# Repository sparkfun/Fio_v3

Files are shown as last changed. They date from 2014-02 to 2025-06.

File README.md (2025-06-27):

Fio v3
======

[Fio v3  
*Fio v3-ATmega32U4 (DEV-11520)*](https://www.sparkfun.com/products/11520)

The Fio v3 is a ATmega32U4 powered system, similar to the ARduino Fio. This board is compatible with a Lipo battery and XBees, and 
runs at 3.3v and 8MHz. 

Repository Contents
-------------------
* **/Firmware** - Arduino example code used in the hookup guide
* **/Hardware** - All Eagle design files (.brd, .sch, .STL)
* **/Production** - Test bed files and production panel files

Documentation
--------------
* **[Hookup Guide](https://learn.sparkfun.com/tutorials/pro-micro--fio-v3-hookup-guide)** - Basic hookup guide for the FioV3.
* **[SparkFun Arduino Board Addon](https://github.com/sparkfun/Arduino_Boards/)** - Arduino board addon for FioV3.
 
License Information
-------------------
This product is _**open source**_! 

Please review the LICENSE.md file for license information. 

If you have any questions or concerns on licensing, please contact techsupport@sparkfun.com.

Distributed as-is; no warranty is given.

- Your friends at SparkFun.

_<COLLABORATION CREDIT>_

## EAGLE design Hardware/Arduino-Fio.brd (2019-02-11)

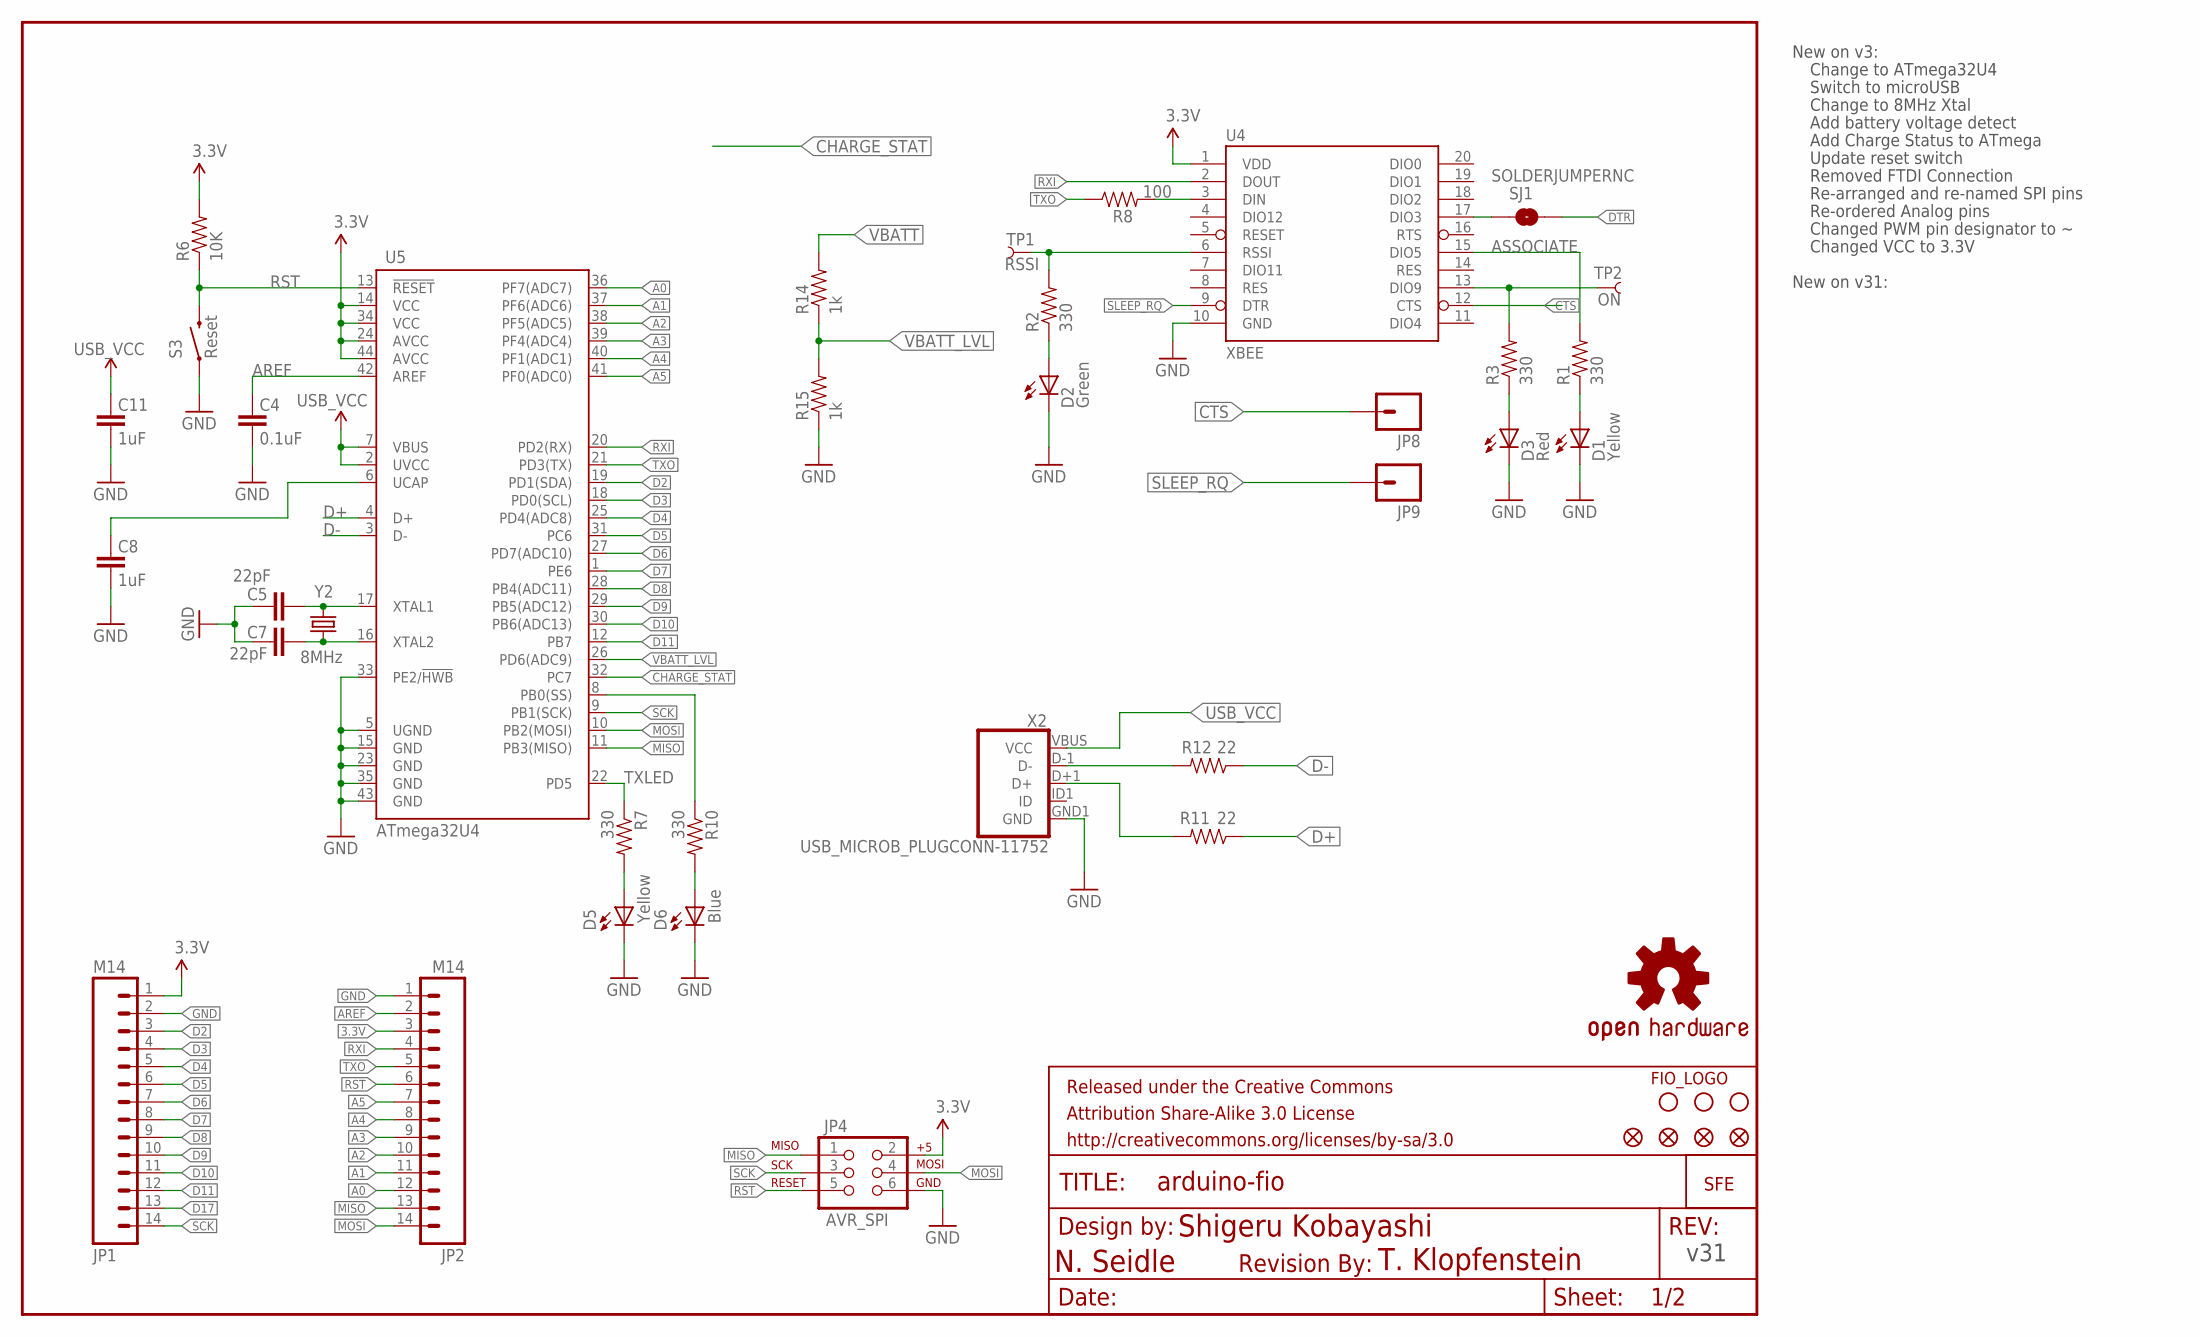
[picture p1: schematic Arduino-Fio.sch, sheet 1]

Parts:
C4: 0.1uF; 0603-CAP
C5, C7: 22pF; 0603-CAP
C8, C11: 1uF; 0603-CAP
D1, D5: Yellow; LED-0603
D2: Green; LED-0603
D3: Red; LED-0603
D6: Blue; LED-0603
FRAME1: FRAME-LETTER; CREATIVE_COMMONS
JP1, JP2: M14; 1X14
JP4: AVR_SPI; 2X3
JP5, JP16, JP17: STAND-OFF
JP8, JP9: M01PTH; 1X01
JP10, JP11, JP12, JP13: FIDUCIALUFIDUCIAL; FIDUCIAL-1X2
LOGO1: OSHW-LOGOL; OSHW-LOGO-L
R1, R2, R3, R7, R10: 330; 0603-RES
R6: 10K; 0603-RES
R8: 100; 0603-RES
R11, R12: 22; 0603-RES
R14, R15: 1k; 0603-RES
S3: Reset; TACTILE_SWITCH_SMD
SJ1: SOLDERJUMPERNC; SJ_2S
TP1: RSSI; PAD.03X.05
TP2: ON; PAD.03X.05
U4: XBEE; XBEE-SMD
U5: ATmega32U4; QFN-44-NOPAD_1:1
U$1: LOGO-SFENEW; SFE-NEW-WEBLOGO
U$2: REVISION
U$6: FIO_LOGOV2; FUNNEL_LOGO_BOTTOM_V2
X2: USB_MICROB_PLUGCONN-11752; USB-B-MICRO-SMD_V03
Y2: 8MHz; CRYSTAL-SMD-5X3

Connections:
3.3V: JP1.1, JP2.3, JP4.2, R6.2, U4.1 (VDD), U5.14 (VCC), U5.24 (AVCC), U5.34 (VCC), U5.44 (AVCC); also elsewhere on the board
A0: JP2.12, U5.36 (PF7(ADC7))
A1: JP2.11, U5.37 (PF6(ADC6))
A2: JP2.10, U5.38 (PF5(ADC5))
A3: JP2.9, U5.39 (PF4(ADC4))
A4: JP2.8, U5.40 (PF1(ADC1))
A5: JP2.7, U5.41 (PF0(ADC0))
AREF: C4.2, JP2.2, U5.42 (AREF)
ASSOCIATE: R1.2, U4.15 (DIO5)
CHARGE_STAT: U5.32 (PC7); also elsewhere on the board
CTS: JP8.1, U4.12 (CTS)
D2: JP1.3, U5.19 (PD1(SDA))
D3: JP1.4, U5.18 (PD0(SCL))
D4: JP1.5, U5.25 (PD4(ADC8))
D5: JP1.6, U5.31 (PC6)
D6: JP1.7, U5.27 (PD7(ADC10))
D7: JP1.8, U5.1 (PE6)
D8: JP1.9, U5.28 (PB4(ADC11))
D9: JP1.10, U5.29 (PB5(ADC12))
D10: JP1.11, U5.30 (PB6(ADC13))
D11: JP1.12, U5.12 (PB7)
D17: JP1.13, R10.1, U5.8 (PB0(SS))
D+: R11.1, U5.4 (D+)
D-: R12.1, U5.3 (D-)
DTR: SJ1.2
GND: C4.1, C5.2, C7.2, C8.1, C11.1, D1.C, D2.C, D3.C, D5.C, D6.C, JP1.2, JP2.1, JP4.6, R15.1, S3.1, U4.10 (GND), U5.5 (UGND), U5.15 (GND), U5.23 (GND), U5.33 (PE2/!HWB), U5.35 (GND), U5.43 (GND), X2.GND1 (GND); also elsewhere on the board
MISO: JP2.13, JP4.1, U5.11 (PB3(MISO))
MOSI: JP2.14, JP4.4, U5.10 (PB2(MOSI))
unnamed: R3.2, TP2.P$1, U4.13 (DIO9)
unnamed: D1.A, R1.1
unnamed: D2.A, R2.1
unnamed: R2.2, TP1.P$1, U4.6 (RSSI)
unnamed: R11.2, X2.D+1 (D+)
unnamed: D3.A, R3.1
unnamed: R8.2, U4.3 (DIN)
unnamed: SJ1.1, U4.17 (DIO3)
unnamed: D5.A, R7.2
unnamed: C7.1, U5.16 (XTAL2), Y2.1
unnamed: C5.1, U5.17 (XTAL1), Y2.3 (2)
unnamed: D6.A, R10.2
unnamed: R12.2, X2.D-1 (D-)
RST: JP2.6, JP4.5, R6.1, S3.3 (2), U5.13 (!RESET)
RXI: JP2.4, U4.2 (DOUT), U5.20 (PD2(RX))
SCK: JP1.14, JP4.3, U5.9 (PB1(SCK))
SLEEP_RQ: JP9.1, U4.9 (DTR)
TXLED: R7.1, U5.22 (PD5)
TXO: JP2.5, R8.1, U5.21 (PD3(TX))
UCAP: C8.2, U5.6 (UCAP)
USB_VCC: C11.2, U5.2 (UVCC), U5.7 (VBUS), X2.VBUS (VCC); also elsewhere on the board
VBATT: R14.2; also elsewhere on the board
VBATT_LVL: R14.1, R15.2, U5.26 (PD6(ADC9))

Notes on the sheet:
Shigeru Kobayashi
Change to ATmega32U4
Switch to microUSB
New on v3:
Change to 8MHz Xtal
Add battery voltage detect
Add Charge Status to ATmega
Update reset switch
Removed FTDI Connection
Re-arranged and re-named SPI pins
Re-ordered Analog pins
Changed PWM pin designator to ~
Changed VCC to 3.3V
New on v31:
v31
N. Seidle
T. Klopfenstein

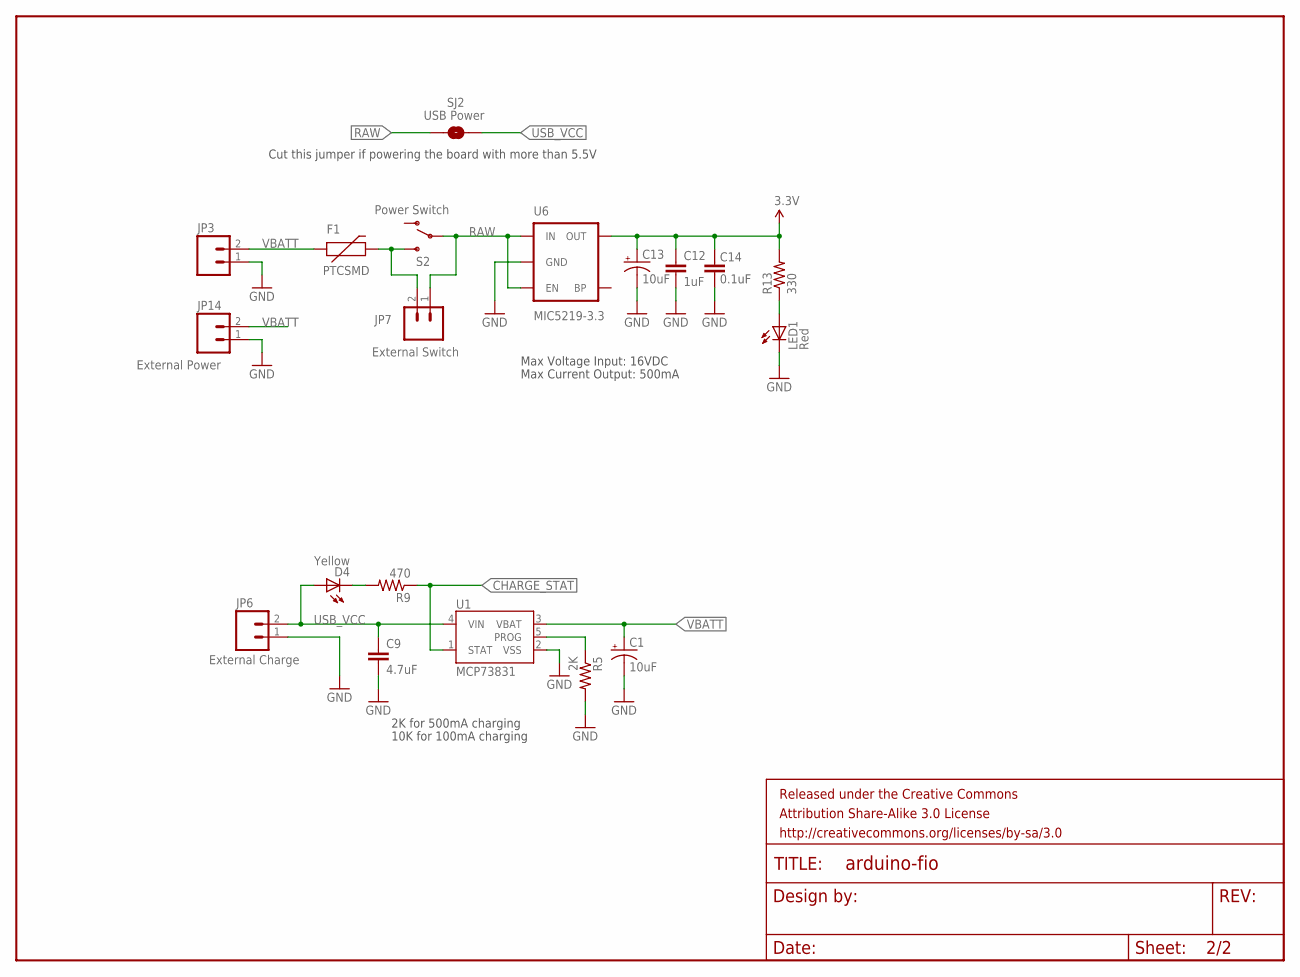
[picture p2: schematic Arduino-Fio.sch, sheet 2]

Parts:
C1, C13: 10uF; EIA3216
C9: 4.7uF; 0603-CAP
C12: 1uF; 0603-CAP
C14: 0.1uF; 0603-CAP
D4: Yellow; LED-0603
F1: PTCSMD; PTC-1206
FRAME2: FRAME-LETTER; CREATIVE_COMMONS
JP3: M02-JST-2MM-SMT; JST-2-SMD
JP6: External Charge; 1X02
JP7: External Switch; 1X02
JP14: External Power; 1X02
LED1: Red; LED-0603
R5: 2K; 0603-RES
R9: 470; 0603-RES
R13: 330; 0603-RES
S2: Power Switch; AYZ0202
SJ2: USB Power; SJ_2S-TRACE
U1: MCP73831; SOT23-5
U6: MIC5219-3.3; SOT23-5

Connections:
3.3V: C12.1, C13.A (+), C14.2, R13.2, U6.5 (OUT); also elsewhere on the board
CHARGE_STAT: R9.1, U1.1 (STAT); also elsewhere on the board
GND: C1.C (-), C9.2, C12.2, C13.C (-), C14.1, JP3.1, JP6.1, JP14.1, LED1.C, R5.2, U1.2 (VSS), U6.2 (GND); also elsewhere on the board
unnamed: D4.C, R9.2
unnamed: F1.2, JP7.2, S2.3 (S)
unnamed: R5.1, U1.5 (PROG)
unnamed: LED1.A, R13.1
RAW: JP7.1, S2.2, SJ2.1, U6.1 (IN), U6.3 (EN)
USB_VCC: C9.1, D4.A, JP6.2, SJ2.2, U1.4 (VIN); also elsewhere on the board
VBATT: C1.A (+), F1.1, JP3.2, JP14.2, U1.3 (VBAT); also elsewhere on the board

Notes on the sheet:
Max Voltage Input: 16VDC
Max Current Output: 500mA
Cut this jumper if powering the board with more than 5.5V
2K for 500mA charging
10K for 100mA charging

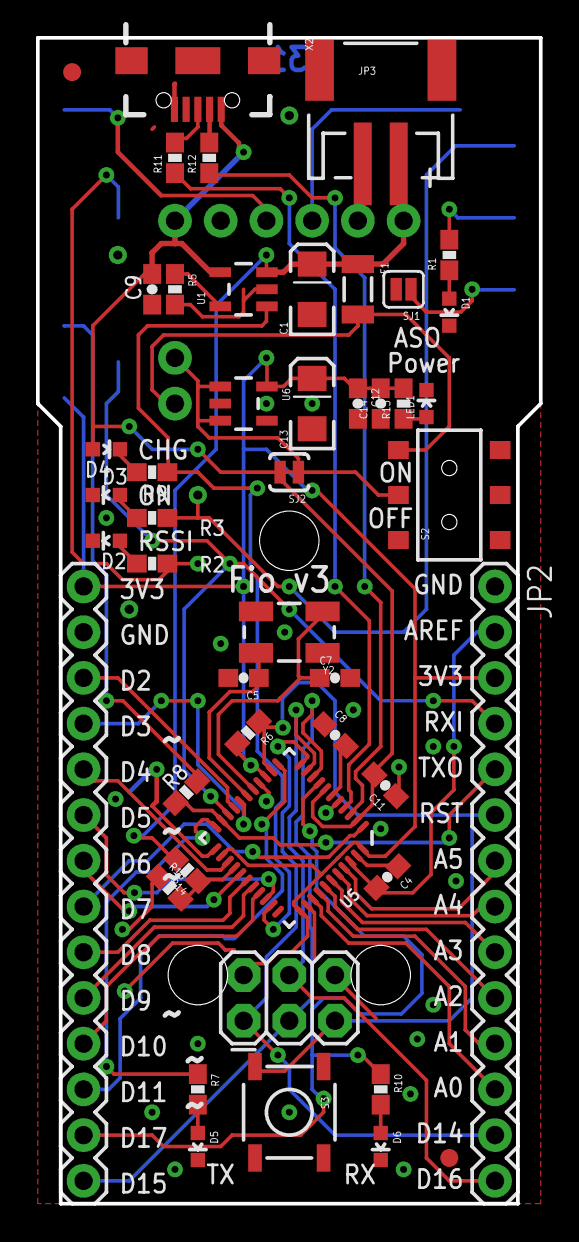
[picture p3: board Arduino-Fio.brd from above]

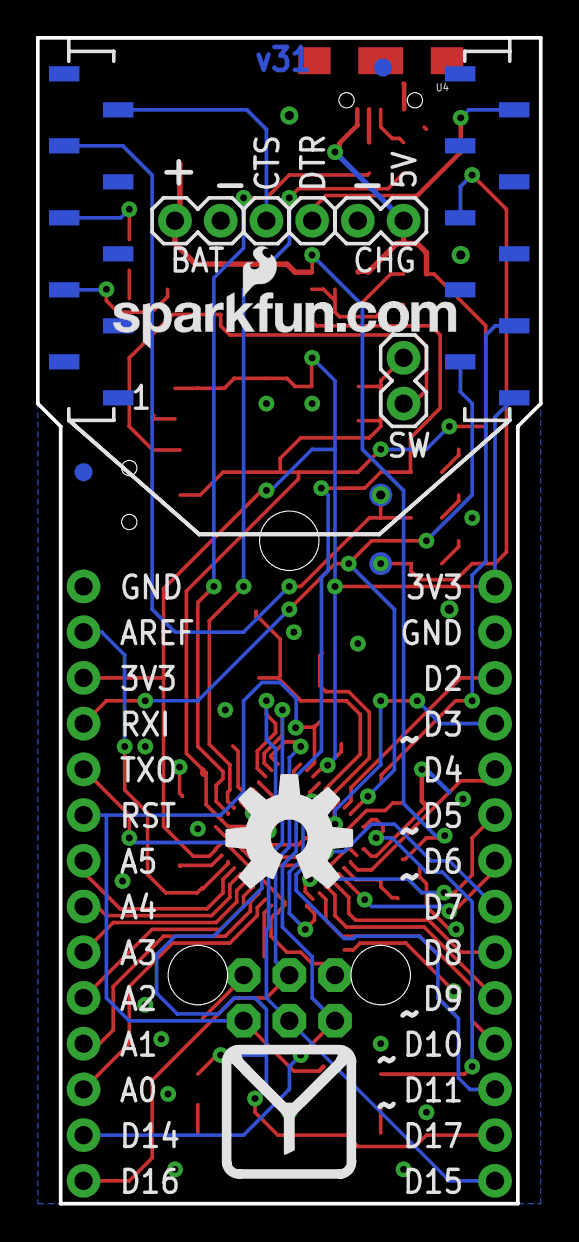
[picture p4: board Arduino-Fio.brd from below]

Board: 2 copper layers, 27.9 x 64.8 mm, 66 parts (12 on the bottom side), 55 nets.

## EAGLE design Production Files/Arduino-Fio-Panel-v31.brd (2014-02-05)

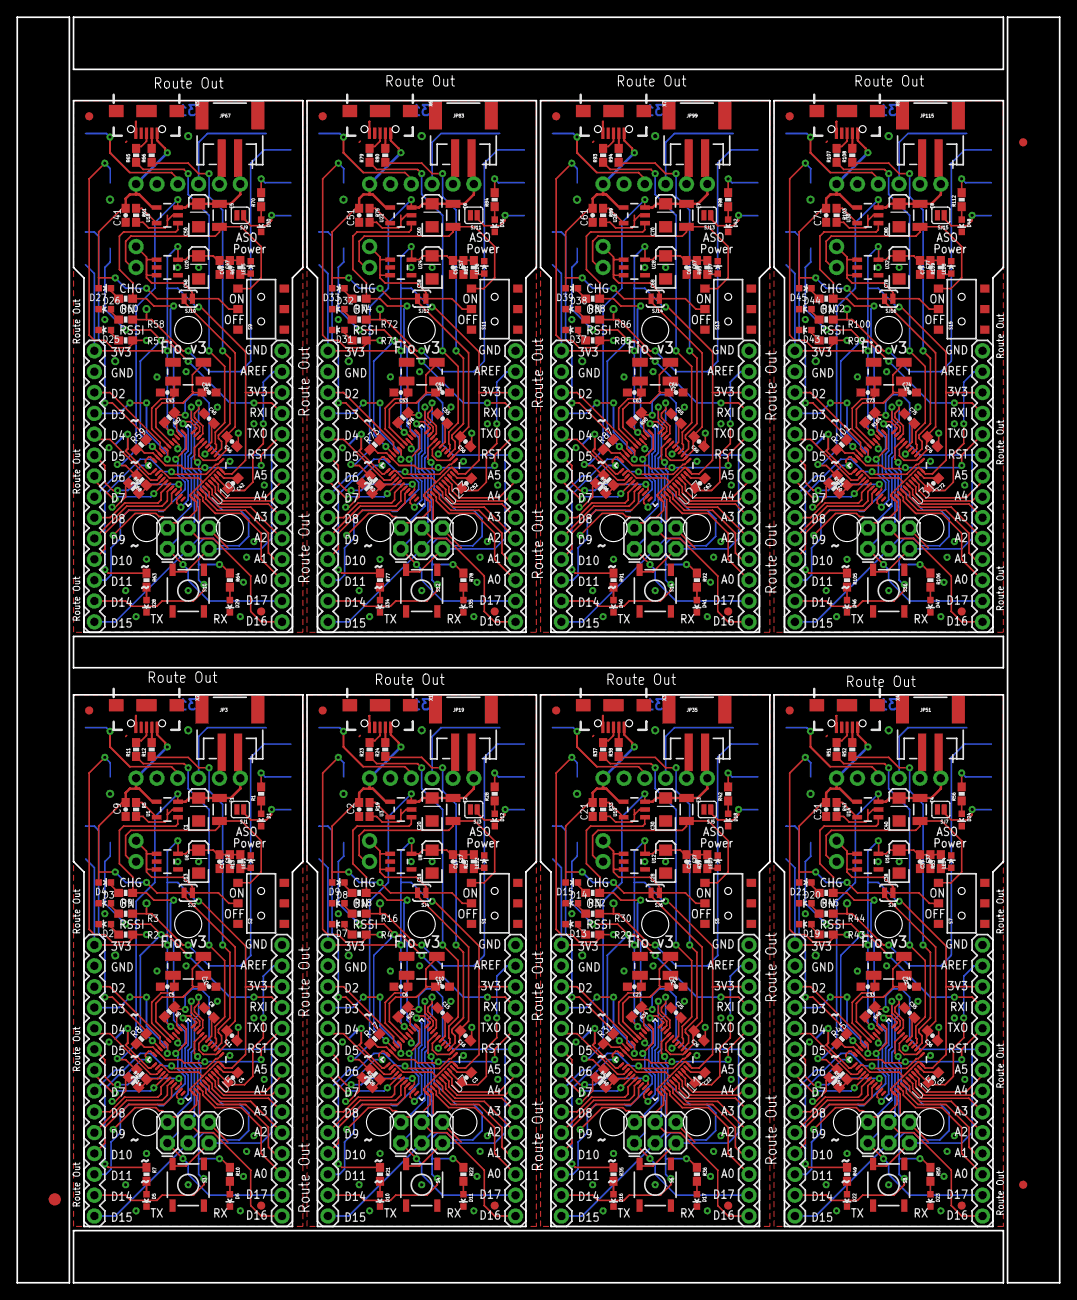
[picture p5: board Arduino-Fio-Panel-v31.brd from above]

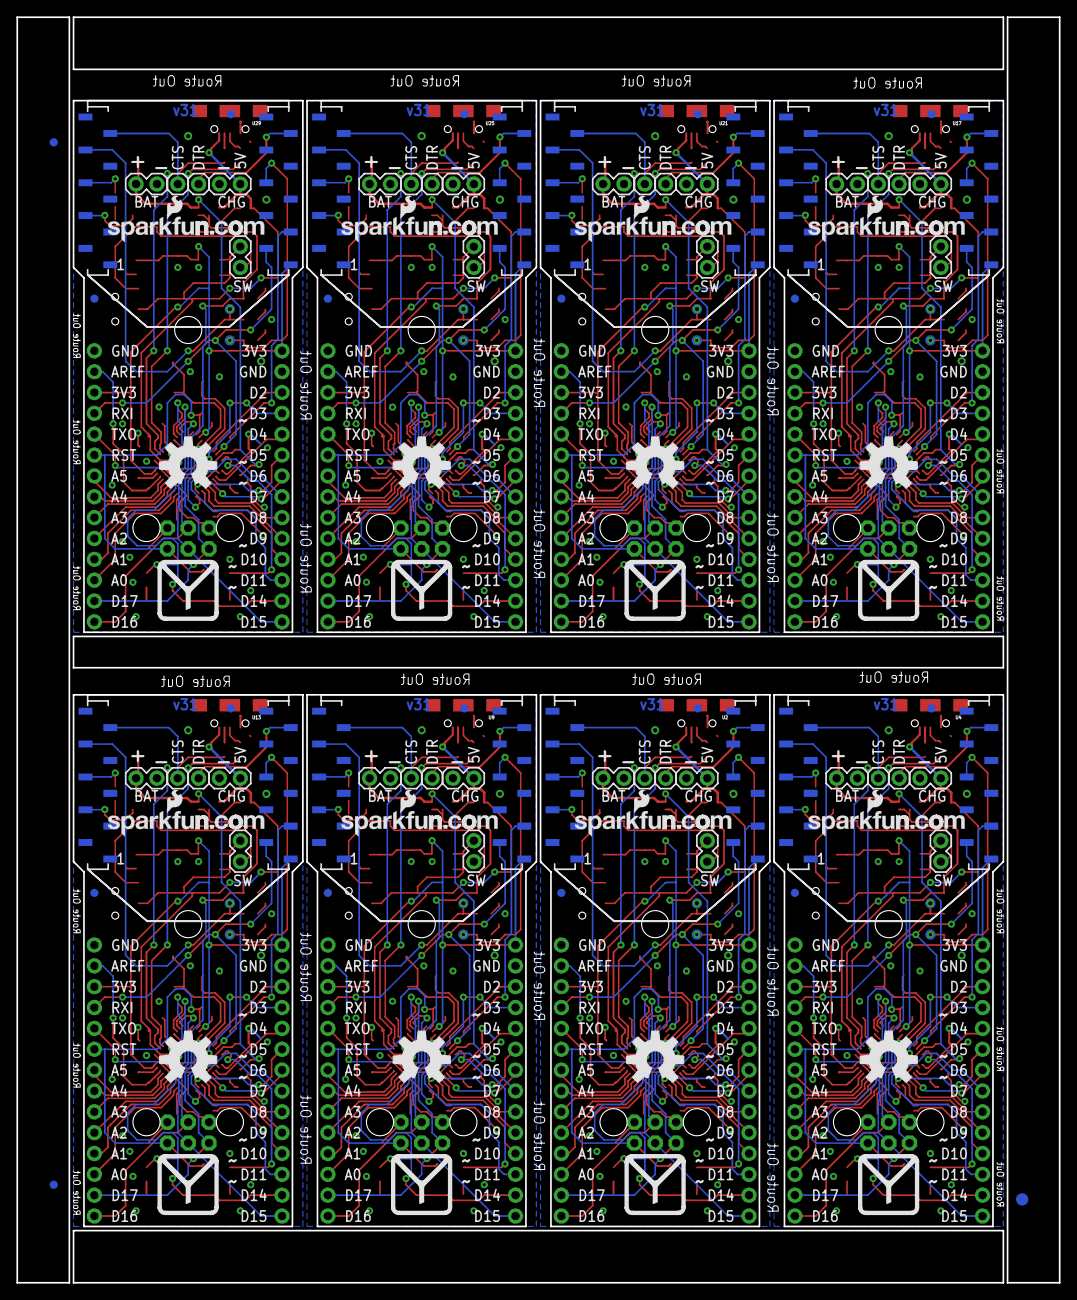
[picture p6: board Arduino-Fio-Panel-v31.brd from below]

Board: 2 copper layers, 127.0 x 154.2 mm, 510 parts (99 on the bottom side), 440 nets.

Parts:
C1, C13, C18, C20, C28, C30, C38, C40, C48, C50, C58, C60, C68, C70, C78, C80: 10uF; EIA3216
C2, C9, C21, C31, C41, C51, C61, C71: 4.7uF; 0603-CAP
C3, C4, C14, C19, C22, C29, C32, C39, C42, C49, C52, C59, C62, C69, C72, C79: 0.1uF; 0603-CAP
C5, C6, C7, C10, C23, C24, C33, C34, C43, C44, C53, C54, C63, C64, C73, C74: 22pF; 0603-CAP
C8, C11, C12, C15, C16, C17, C25, C26, C27, C35, C36, C37, C45, C46, C47, C55, C56, C57, C65, C66, C67, C75, C76, C77: 1uF; 0603-CAP
D1, D4, D5, D9, D10, D12, D15, D16, D18, D21, D22, D24, D27, D28, D30, D33, D34, D36, D39, D40, D42, D45, D46, D48: Yellow; LED-0603
D2, D7, D13, D19, D25, D31, D37, D43: Green; LED-0603
D3, D8, D14, D20, D26, D32, D38, D44: Red; LED-0603
D6, D11, D17, D23, D29, D35, D41, D47: Blue; LED-0603
E$1, E$2: FIDUCIAL-1.5X3
E$3, E$4, E$5, E$6: FIDUCIAL-1X2
F1, F2, F3, F4, F5, F6, F7, F8: PTCSMD; PTC-1206
JP1, JP2, JP18, JP29, JP34, JP45, JP50, JP61, JP66, JP77, JP82, JP93, JP98, JP109, JP114, JP125: M14; 1X14
JP3, JP19, JP35, JP51, JP67, JP83, JP99, JP115: JST-2-SMD
JP4, JP15, JP33, JP49, JP65, JP81, JP97, JP113: AVR_SPI; 2X3
JP5, JP16, JP17, JP30, JP31, JP32, JP46, JP47, JP48, JP62, JP63, JP64, JP78, JP79, JP80, JP94, JP95, JP96, JP110, JP111, JP112, JP126, JP127, JP128: STAND-OFF
JP6, JP21, JP37, JP53, JP69, JP85, JP101, JP117: External Charge; 1X02
JP7, JP22, JP38, JP54, JP70, JP86, JP102, JP118: External Switch; 1X02
JP8, JP9, JP23, JP24, JP39, JP40, JP55, JP56, JP71, JP72, JP87, JP88, JP103, JP104, JP119, JP120: 1X01
JP10, JP11, JP12, JP13, JP25, JP26, JP27, JP28, JP41, JP42, JP43, JP44, JP57, JP58, JP59, JP60, JP73, JP74, JP75, JP76, JP89, JP90, JP91, JP92, JP105, JP106, JP107, JP108, JP121, JP122, JP123, JP124: FIDUCIALUFIDUCIAL; FIDUCIAL-1X2
JP14, JP20, JP36, JP52, JP68, JP84, JP100, JP116: External Power; 1X02
LED1, LED2, LED3, LED4, LED5, LED6, LED7, LED8: Red; LED-0603
LOGO1, LOGO2, LOGO3, LOGO4, LOGO5, LOGO6, LOGO7, LOGO8: OSHW-LOGOL; OSHW-LOGO-L
R1, R2, R3, R4, R7, R10, R13, R16, R21, R22, R25, R28, R29, R30, R35, R36, R39, R42, R43, R44, R49, R50, R53, R56, R57, R58, R63, R64, R67, R70, R71, R72, R77, R78, R81, R84, R85, R86, R91, R92, R95, R98, R99, R100, R105, R106, R109, R112: 330; 0603-RES
R5, R19, R33, R47, R61, R75, R89, R103: 2K; 0603-RES
R6, R20, R34, R48, R62, R76, R90, R104: 10K; 0603-RES
R8, R17, R31, R45, R59, R73, R87, R101: 100; 0603-RES
R9, R18, R32, R46, R60, R74, R88, R102: 470; 0603-RES
R11, R12, R23, R24, R37, R38, R51, R52, R65, R66, R79, R80, R93, R94, R107, R108: 22; 0603-RES
R14, R15, R26, R27, R40, R41, R54, R55, R68, R69, R82, R83, R96, R97, R110, R111: 1k; 0603-RES
S1, S2, S5, S7, S9, S11, S13, S15: Power Switch; AYZ0202
S3, S4, S6, S8, S10, S12, S14, S16: Reset; TACTILE_SWITCH_SMD
SJ1, SJ3, SJ5, SJ7, SJ9, SJ11, SJ13, SJ15: SOLDERJUMPERNC; SJ_2S
SJ2, SJ4, SJ6, SJ8, SJ10, SJ12, SJ14, SJ16: USB Power; SJ_2S-TRACE
TP1, TP3, TP5, TP7, TP9, TP11, TP13, TP15: RSSI; PAD.03X.05
TP2, TP4, TP6, TP8, TP10, TP12, TP14, TP16: ON; PAD.03X.05
U1, U3, U10, U14, U18, U22, U26, U30: MCP73831; SOT23-5
U2, U4, U9, U13, U17, U21, U25, U29: XBEE; XBEE-SMD
U5, U7, U11, U15, U19, U23, U27, U31: ATMEGA32U4; QFN-44-NOPAD_1:1
U6, U8, U12, U16, U20, U24, U28, U32: MIC5219-3.3; SOT23-5
U$1, U$2, U$4, U$7, U$9, U$11, U$13, U$15: LOGO-SFENEW; SFE-NEW-WEBLOGO
U$3, U$5, U$6, U$8, U$10, U$12, U$14, U$16: FIO_LOGOV2; FUNNEL_LOGO_BOTTOM_V2
X1, X2, X3, X4, X5, X6, X7, X8: USB_MICROB_PLUGCONN-11752; USB-B-MICRO-SMD_V03
Y1, Y2, Y3, Y4, Y5, Y6, Y7, Y8: 8MHz; CRYSTAL-SMD-5X3

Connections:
3.3V: C12.1, C13.A, C14.2, JP1.1, JP2.3, JP4.2, R6.2, R13.2, U4.1, U5.14, U5.24, U5.34, U5.44, U6.5
3.3V1: C17.1, C18.A, C19.2, JP15.2, JP18.1, JP29.3, R20.2, R25.2, U2.1, U7.14, U7.24, U7.34, U7.44, U8.5
3.3V2: C27.1, C28.A, C29.2, JP33.2, JP34.1, JP45.3, R34.2, R39.2, U9.1, U11.14, U11.24, U11.34, U11.44, U12.5
3.3V3: C37.1, C38.A, C39.2, JP49.2, JP50.1, JP61.3, R48.2, R53.2, U13.1, U15.14, U15.24, U15.34, U15.44, U16.5
3.3V4: C47.1, C48.A, C49.2, JP65.2, JP66.1, JP77.3, R62.2, R67.2, U17.1, U19.14, U19.24, U19.34, U19.44, U20.5
3.3V5: C57.1, C58.A, C59.2, JP81.2, JP82.1, JP93.3, R76.2, R81.2, U21.1, U23.14, U23.24, U23.34, U23.44, U24.5
3.3V6: C67.1, C68.A, C69.2, JP97.2, JP98.1, JP109.3, R90.2, R95.2, U25.1, U27.14, U27.24, U27.34, U27.44, U28.5
3.3V7: C77.1, C78.A, C79.2, JP113.2, JP114.1, JP125.3, R104.2, R109.2, U29.1, U31.14, U31.24, U31.34, U31.44, U32.5
A0: JP2.12, U5.36
A1: JP2.11, U5.37
A2: JP2.10, U5.38
A3: JP2.9, U5.39
A4: JP2.8, U5.40
A5: JP2.7, U5.41
A6: JP29.12, U7.36
A7: JP29.11, U7.37
A8: JP29.10, U7.38
A9: JP29.9, U7.39
A10: JP29.8, U7.40
A11: JP29.7, U7.41
A12: JP45.12, U11.36
A13: JP45.11, U11.37
A14: JP45.10, U11.38
A15: JP45.9, U11.39
A16: JP45.8, U11.40
A17: JP45.7, U11.41
A18: JP61.12, U15.36
A19: JP61.11, U15.37
A20: JP61.10, U15.38
A21: JP61.9, U15.39
A22: JP61.8, U15.40
A23: JP61.7, U15.41
A24: JP77.12, U19.36
A25: JP77.11, U19.37
A26: JP77.10, U19.38
A27: JP77.9, U19.39
A28: JP77.8, U19.40
A29: JP77.7, U19.41
A30: JP93.12, U23.36
A31: JP93.11, U23.37
A32: JP93.10, U23.38
A33: JP93.9, U23.39
A34: JP93.8, U23.40
A35: JP93.7, U23.41
A36: JP109.12, U27.36
A37: JP109.11, U27.37
A38: JP109.10, U27.38
A39: JP109.9, U27.39
A40: JP109.8, U27.40
A41: JP109.7, U27.41
A42: JP125.12, U31.36
A43: JP125.11, U31.37
A44: JP125.10, U31.38
A45: JP125.9, U31.39
A46: JP125.8, U31.40
A47: JP125.7, U31.41
AREF: C4.2, JP2.2, U5.42
AREF1: C3.2, JP29.2, U7.42
AREF2: C22.2, JP45.2, U11.42
AREF3: C32.2, JP61.2, U15.42
AREF4: C42.2, JP77.2, U19.42
AREF5: C52.2, JP93.2, U23.42
AREF6: C62.2, JP109.2, U27.42
AREF7: C72.2, JP125.2, U31.42
ASSOCIATE: R1.2, U4.15
ASSOCIATE1: R28.2, U2.15
ASSOCIATE2: R42.2, U9.15
ASSOCIATE3: R56.2, U13.15
ASSOCIATE4: R70.2, U17.15
ASSOCIATE5: R84.2, U21.15
ASSOCIATE6: R98.2, U25.15
ASSOCIATE7: R112.2, U29.15
CHARGE_STAT: R9.1, U1.1, U5.32
CHARGE_STAT1: R18.1, U3.1, U7.32
CHARGE_STAT2: R32.1, U10.1, U11.32
CHARGE_STAT3: R46.1, U14.1, U15.32
CHARGE_STAT4: R60.1, U18.1, U19.32
CHARGE_STAT5: R74.1, U22.1, U23.32
CHARGE_STAT6: R88.1, U26.1, U27.32
CHARGE_STAT7: R102.1, U30.1, U31.32
CTS: JP8.1, U4.12
CTS1: JP23.1, U2.12
CTS2: JP39.1, U9.12
CTS3: JP55.1, U13.12
CTS4: JP71.1, U17.12
CTS5: JP87.1, U21.12
CTS6: JP103.1, U25.12
CTS7: JP119.1, U29.12
D1: JP18.3, U7.19
D2: JP1.3, U5.19
D3: JP1.4, U5.18
D4: JP1.5, U5.25
D5: JP1.6, U5.31
D6: JP1.7, U5.27
D7: JP1.8, U5.1
D8: JP1.9, U5.28
D9: JP1.10, U5.29
D10: JP1.11, U5.30
D11: JP1.12, U5.12
D12: JP18.4, U7.18
D13: JP18.5, U7.25
D14: JP1.13, R10.1, U5.8
D15: JP18.6, U7.31
D16: JP18.7, U7.27
D17: JP18.9, U7.28
D18: JP18.11, U7.30
D19: JP18.8, U7.1
D20: JP18.10, U7.29
D21: JP18.12, U7.12
D22: JP18.13, R22.1, U7.8
D23: JP34.3, U11.19
D24: JP34.4, U11.18
D25: JP34.5, U11.25
D26: JP34.6, U11.31
D27: JP34.7, U11.27
D28: JP34.9, U11.28
D29: JP34.11, U11.30
D30: JP34.8, U11.1
D31: JP34.10, U11.29
D32: JP34.12, U11.12
D33: JP34.13, R36.1, U11.8
D34: JP50.3, U15.19
D35: JP50.4, U15.18
D36: JP50.5, U15.25
D37: JP50.6, U15.31
D38: JP50.7, U15.27
D39: JP50.9, U15.28
D40: JP50.11, U15.30
D41: JP50.8, U15.1
D42: JP50.10, U15.29
D43: JP50.12, U15.12
D44: JP50.13, R50.1, U15.8
D45: JP66.3, U19.19
D46: JP66.4, U19.18
D47: JP66.5, U19.25
D48: JP66.6, U19.31
D49: JP66.7, U19.27
D50: JP66.9, U19.28
D51: JP66.11, U19.30
D52: JP66.8, U19.1
D53: JP66.10, U19.29
D54: JP66.12, U19.12
D55: JP66.13, R64.1, U19.8
D56: JP82.3, U23.19
D57: JP82.4, U23.18
D58: JP82.5, U23.25
D59: JP82.6, U23.31
D60: JP82.7, U23.27
D61: JP82.9, U23.28
D62: JP82.11, U23.30
D63: JP82.8, U23.1
D64: JP82.10, U23.29
D65: JP82.12, U23.12
D66: JP82.13, R78.1, U23.8
D67: JP98.3, U27.19
D68: JP98.4, U27.18
D69: JP98.5, U27.25
D70: JP98.6, U27.31
D71: JP98.7, U27.27
D72: JP98.9, U27.28
D73: JP98.11, U27.30
D74: JP98.8, U27.1
D75: JP98.10, U27.29
D76: JP98.12, U27.12
D77: JP98.13, R92.1, U27.8
D78: JP114.3, U31.19
D79: JP114.4, U31.18
D80: JP114.5, U31.25
D81: JP114.6, U31.31
D82: JP114.7, U31.27
D83: JP114.9, U31.28
D84: JP114.11, U31.30
D85: JP114.8, U31.1
D86: JP114.10, U31.29
D87: JP114.12, U31.12
D88: JP114.13, R106.1, U31.8
D+: R11.1, U5.4
D+1: R23.1, U7.4
D+2: R37.1, U11.4
D+3: R51.1, U15.4
D+4: R65.1, U19.4
D+5: R79.1, U23.4
D+6: R93.1, U27.4
D+7: R107.1, U31.4
D-: R12.1, U5.3
D-1: R24.1, U7.3
D-2: R38.1, U11.3
D-3: R52.1, U15.3
D-4: R66.1, U19.3
D-5: R80.1, U23.3
D-6: R94.1, U27.3
D-7: R108.1, U31.3
GND: C1.C, C4.1, C5.2, C7.2, C8.1, C9.2, C11.1, C12.2, C13.C, C14.1, D1.C, D2.C, D3.C, D5.C, D6.C, JP1.2, JP2.1, JP3.1, JP4.6, JP6.1, JP14.1, LED1.C, R5.2, R15.1, S3.1, U1.2, U4.10, U5.5, U5.15, U5.23, U5.33, U5.35, U5.43, U6.2, X2.GND1
GND1: C2.2, C3.1, C6.2, C10.2, C15.1, C16.1, C17.2, C18.C, C19.1, C20.C, D7.C, D8.C, D10.C, D11.C, D12.C, JP15.6, JP18.2, JP19.1, JP20.1, JP21.1, JP29.1, LED2.C, R19.2, R27.1, S4.1, U2.10, U3.2, U7.5, U7.15, U7.23, U7.33, U7.35, U7.43, U8.2, X1.GND1
GND2: C21.2, C22.1, C23.2, C24.2, C25.1, C26.1, C27.2, C28.C, C29.1, C30.C, D13.C, D14.C, D16.C, D17.C, D18.C, JP33.6, JP34.2, JP35.1, JP36.1, JP37.1, JP45.1, LED3.C, R33.2, R41.1, S6.1, U9.10, U10.2, U11.5, U11.15, U11.23, U11.33, U11.35, U11.43, U12.2, X3.GND1
GND3: C31.2, C32.1, C33.2, C34.2, C35.1, C36.1, C37.2, C38.C, C39.1, C40.C, D19.C, D20.C, D22.C, D23.C, D24.C, JP49.6, JP50.2, JP51.1, JP52.1, JP53.1, JP61.1, LED4.C, R47.2, R55.1, S8.1, U13.10, U14.2, U15.5, U15.15, U15.23, U15.33, U15.35, U15.43, U16.2, X4.GND1
GND4: C41.2, C42.1, C43.2, C44.2, C45.1, C46.1, C47.2, C48.C, C49.1, C50.C, D25.C, D26.C, D28.C, D29.C, D30.C, JP65.6, JP66.2, JP67.1, JP68.1, JP69.1, JP77.1, LED5.C, R61.2, R69.1, S10.1, U17.10, U18.2, U19.5, U19.15, U19.23, U19.33, U19.35, U19.43, U20.2, X5.GND1
GND5: C51.2, C52.1, C53.2, C54.2, C55.1, C56.1, C57.2, C58.C, C59.1, C60.C, D31.C, D32.C, D34.C, D35.C, D36.C, JP81.6, JP82.2, JP83.1, JP84.1, JP85.1, JP93.1, LED6.C, R75.2, R83.1, S12.1, U21.10, U22.2, U23.5, U23.15, U23.23, U23.33, U23.35, U23.43, U24.2, X6.GND1
GND6: C61.2, C62.1, C63.2, C64.2, C65.1, C66.1, C67.2, C68.C, C69.1, C70.C, D37.C, D38.C, D40.C, D41.C, D42.C, JP97.6, JP98.2, JP99.1, JP100.1, JP101.1, JP109.1, LED7.C, R89.2, R97.1, S14.1, U25.10, U26.2, U27.5, U27.15, U27.23, U27.33, U27.35, U27.43, U28.2, X7.GND1
GND7: C71.2, C72.1, C73.2, C74.2, C75.1, C76.1, C77.2, C78.C, C79.1, C80.C, D43.C, D44.C, D46.C, D47.C, D48.C, JP113.6, JP114.2, JP115.1, JP116.1, JP117.1, JP125.1, LED8.C, R103.2, R111.1, S16.1, U29.10, U30.2, U31.5, U31.15, U31.23, U31.33, U31.35, U31.43, U32.2, X8.GND1
MISO: JP2.13, JP4.1, U5.11
MISO1: JP15.1, JP29.13, U7.11
MISO2: JP33.1, JP45.13, U11.11
MISO3: JP49.1, JP61.13, U15.11
MISO4: JP65.1, JP77.13, U19.11
MISO5: JP81.1, JP93.13, U23.11
MISO6: JP97.1, JP109.13, U27.11
MISO7: JP113.1, JP125.13, U31.11
MOSI: JP2.14, JP4.4, U5.10
MOSI1: JP15.4, JP29.14, U7.10
MOSI2: JP33.4, JP45.14, U11.10
MOSI3: JP49.4, JP61.14, U15.10
MOSI4: JP65.4, JP77.14, U19.10
MOSI5: JP81.4, JP93.14, U23.10
MOSI6: JP97.4, JP109.14, U27.10
MOSI7: JP113.4, JP125.14, U31.10
unnamed: R3.2, TP2.P$1, U4.13
unnamed: D1.A, R1.1
unnamed: D2.A, R2.1
unnamed: R2.2, TP1.P$1, U4.6
unnamed: R11.2, X2.D+1
unnamed: D3.A, R3.1
unnamed: R8.2, U4.3
unnamed: D4.C, R9.2
unnamed: F1.2, JP7.2, S2.3
unnamed: D7.A, R4.1
unnamed: R5.1, U1.5
unnamed: R4.2, TP3.P$1, U2.6
unnamed: SJ1.1, U4.17
unnamed: D8.A, R16.1
unnamed: D5.A, R7.2
unnamed: C7.1, U5.16, Y2.1
unnamed: C5.1, U5.17, Y2.3
unnamed: R16.2, TP4.P$1, U2.13
unnamed: D6.A, R10.2
unnamed: R12.2, X2.D-1
unnamed: R17.2, U2.3
unnamed: F2.2, JP22.2, S1.3
unnamed: SJ3.1, U2.17
unnamed: R19.1, U3.5
unnamed: D9.C, R18.2
unnamed: D10.A, R21.2
unnamed: C10.1, U7.16, Y1.1
unnamed: C6.1, U7.17, Y1.3
unnamed: D11.A, R22.2
unnamed: R24.2, X1.D-1
unnamed: LED2.A, R25.1
unnamed: D12.A, R28.1
unnamed: R23.2, X1.D+1
unnamed: D13.A, R29.1
unnamed: R29.2, TP5.P$1, U9.6
unnamed: D14.A, R30.1
unnamed: R30.2, TP6.P$1, U9.13
unnamed: LED1.A, R13.1
unnamed: R31.2, U9.3
unnamed: F3.2, JP38.2, S5.3
unnamed: SJ5.1, U9.17
unnamed: R33.1, U10.5
unnamed: D15.C, R32.2
unnamed: D16.A, R35.2
unnamed: C24.1, U11.16, Y3.1
unnamed: C23.1, U11.17, Y3.3
unnamed: D17.A, R36.2
unnamed: R38.2, X3.D-1
unnamed: LED3.A, R39.1
unnamed: D18.A, R42.1
unnamed: R37.2, X3.D+1
unnamed: D19.A, R43.1
unnamed: R43.2, TP7.P$1, U13.6
unnamed: D20.A, R44.1
unnamed: R44.2, TP8.P$1, U13.13
unnamed: R45.2, U13.3
unnamed: F4.2, JP54.2, S7.3
unnamed: SJ7.1, U13.17
unnamed: R47.1, U14.5
unnamed: D21.C, R46.2
unnamed: D22.A, R49.2
unnamed: C34.1, U15.16, Y4.1
unnamed: C33.1, U15.17, Y4.3
unnamed: D23.A, R50.2
unnamed: R52.2, X4.D-1
unnamed: LED4.A, R53.1
unnamed: D24.A, R56.1
unnamed: R51.2, X4.D+1
unnamed: D25.A, R57.1
unnamed: R57.2, TP9.P$1, U17.6
unnamed: D26.A, R58.1
unnamed: R58.2, TP10.P$1, U17.13
unnamed: R59.2, U17.3
unnamed: F5.2, JP70.2, S9.3
unnamed: SJ9.1, U17.17
unnamed: R61.1, U18.5
unnamed: D27.C, R60.2
unnamed: D28.A, R63.2
unnamed: C44.1, U19.16, Y5.1
unnamed: C43.1, U19.17, Y5.3
unnamed: D29.A, R64.2
unnamed: R66.2, X5.D-1
unnamed: LED5.A, R67.1
unnamed: D30.A, R70.1
unnamed: R65.2, X5.D+1
unnamed: D31.A, R71.1
unnamed: R71.2, TP11.P$1, U21.6
unnamed: D32.A, R72.1
unnamed: R72.2, TP12.P$1, U21.13
unnamed: R73.2, U21.3
unnamed: F6.2, JP86.2, S11.3
unnamed: SJ11.1, U21.17
unnamed: R75.1, U22.5
unnamed: D33.C, R74.2
unnamed: D34.A, R77.2
unnamed: C54.1, U23.16, Y6.1
unnamed: C53.1, U23.17, Y6.3
unnamed: D35.A, R78.2
unnamed: R80.2, X6.D-1
unnamed: LED6.A, R81.1
unnamed: D36.A, R84.1
unnamed: R79.2, X6.D+1
unnamed: D37.A, R85.1
unnamed: R85.2, TP13.P$1, U25.6
unnamed: D38.A, R86.1
unnamed: R86.2, TP14.P$1, U25.13
unnamed: R87.2, U25.3
unnamed: F7.2, JP102.2, S13.3
unnamed: SJ13.1, U25.17
unnamed: R89.1, U26.5
unnamed: D39.C, R88.2
unnamed: D40.A, R91.2
unnamed: C64.1, U27.16, Y7.1
unnamed: C63.1, U27.17, Y7.3
unnamed: D41.A, R92.2
unnamed: R94.2, X7.D-1
unnamed: LED7.A, R95.1
unnamed: D42.A, R98.1
unnamed: R93.2, X7.D+1
unnamed: D43.A, R99.1
unnamed: R99.2, TP15.P$1, U29.6
unnamed: D44.A, R100.1
unnamed: R100.2, TP16.P$1, U29.13
unnamed: R101.2, U29.3
unnamed: F8.2, JP118.2, S15.3
unnamed: SJ15.1, U29.17
unnamed: R103.1, U30.5
unnamed: D45.C, R102.2
unnamed: D46.A, R105.2
unnamed: C74.1, U31.16, Y8.1
unnamed: C73.1, U31.17, Y8.3
unnamed: D47.A, R106.2
unnamed: R108.2, X8.D-1
unnamed: LED8.A, R109.1
unnamed: D48.A, R112.1
unnamed: R107.2, X8.D+1
RAW: JP7.1, S2.2, SJ2.1, U6.1, U6.3
RAW1: JP22.1, S1.2, SJ4.1, U8.1, U8.3
RAW2: JP38.1, S5.2, SJ6.1, U12.1, U12.3
RAW3: JP54.1, S7.2, SJ8.1, U16.1, U16.3
RAW4: JP70.1, S9.2, SJ10.1, U20.1, U20.3
RAW5: JP86.1, S11.2, SJ12.1, U24.1, U24.3
RAW6: JP102.1, S13.2, SJ14.1, U28.1, U28.3
RAW7: JP118.1, S15.2, SJ16.1, U32.1, U32.3
RST: JP2.6, JP4.5, R6.1, S3.3, U5.13
RST1: JP15.5, JP29.6, R20.1, S4.3, U7.13
RST2: JP33.5, JP45.6, R34.1, S6.3, U11.13
RST3: JP49.5, JP61.6, R48.1, S8.3, U15.13
RST4: JP65.5, JP77.6, R62.1, S10.3, U19.13
RST5: JP81.5, JP93.6, R76.1, S12.3, U23.13
RST6: JP97.5, JP109.6, R90.1, S14.3, U27.13
RST7: JP113.5, JP125.6, R104.1, S16.3, U31.13
RXI: JP2.4, U4.2, U5.20
RXI1: JP29.4, U2.2, U7.20
RXI2: JP45.4, U9.2, U11.20
RXI3: JP61.4, U13.2, U15.20
RXI4: JP77.4, U17.2, U19.20
RXI5: JP93.4, U21.2, U23.20
RXI6: JP109.4, U25.2, U27.20
RXI7: JP125.4, U29.2, U31.20
SCK: JP1.14, JP4.3, U5.9
SCK1: JP15.3, JP18.14, U7.9
SCK2: JP33.3, JP34.14, U11.9
SCK3: JP49.3, JP50.14, U15.9
SCK4: JP65.3, JP66.14, U19.9
SCK5: JP81.3, JP82.14, U23.9
SCK6: JP97.3, JP98.14, U27.9
SCK7: JP113.3, JP114.14, U31.9
SLEEP_RQ: JP9.1, U4.9
SLEEP_RQ1: JP24.1, U2.9
SLEEP_RQ2: JP40.1, U9.9
SLEEP_RQ3: JP56.1, U13.9
SLEEP_RQ4: JP72.1, U17.9
SLEEP_RQ5: JP88.1, U21.9
SLEEP_RQ6: JP104.1, U25.9
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

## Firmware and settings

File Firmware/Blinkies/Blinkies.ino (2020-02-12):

/* Pro Micro Test Code
   by: Nathan Seidle
   modified by: Jim Lindblom
   SparkFun Electronics
   date: September 16, 2013
   license: Public Domain - please use this code however you'd like.
   It's provided as a learning tool.

   This code is provided to show how to control the SparkFun
   ProMicro's TX and RX LEDs within a sketch. It also serves
   to explain the difference between Serial.print() and
   Serial1.print().
*/

int RXLED = 17;  // The RX LED has a defined Arduino pin
// Note: The TX LED was not so lucky, we'll need to use pre-defined
// macros (TXLED1, TXLED0) to control that.
// (We could use the same macros for the RX LED too -- RXLED1,
//  and RXLED0.)

void setup()
{
  pinMode(RXLED, OUTPUT);  // Set RX LED as an output
  // TX LED is set as an output behind the scenes

  Serial.begin(9600); //This pipes to the serial monitor
  Serial.println("Initialize Serial Monitor");

  Serial1.begin(9600); //This is the UART, pipes to sensors attached to board
  Serial1.println("Initialize Serial Hardware UART Pins");
}

void loop()
{
  Serial.println("Hello world!");  // Print "Hello World" to the Serial Monitor
  Serial1.println("Hello! Can anybody hear me?");  // Print "Hello!" over hardware UART

  digitalWrite(RXLED, LOW);   // set the RX LED ON
  TXLED0; //TX LED is not tied to a normally controlled pin so a macro is needed, turn LED OFF
  delay(1000);              // wait for a second

  digitalWrite(RXLED, HIGH);    // set the RX LED OFF
  TXLED1; //TX LED macro to turn LED ON
  delay(1000);              // wait for a second
}

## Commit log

2013-07-03 Hardware v31 upload
    [Arduino-Fio.brd, Arduino-Fio.sch]
2013-11-07 Midway hardware update
    [Arduino-Fio.brd, Arduino-Fio.sch]
2014-01-02 Fixing USB trace issue
    [Arduino-Fio.brd]
2014-01-31 Fixing schematic frame
    [Arduino-Fio.brd, Arduino-Fio.sch]
2014-02-05 Moved bottom fiducials to clear the Xbee headers
    [Arduino-Fio.brd]
2014-02-05 Created Panel v31
    [Arduino-Fio-Panel-v31.brd]
2018-01-29 Update README.md
    * Link Tutorial
    * Link Board Addon repo
    *Update License
2019-02-11 Update Labeling
    Updated individual board's silkscreen to correct pins to match the connection to the ATmega32U4 and Arduino core files:
    * D17 | RxLED | SS
    * D14 | MISO
    Replace schematic package to match silkscreen from Brent's fix => [ https://github.com/sparkfun/SparkFun-Eagle-Libraries/issues/77#issuecomment-89820839 ]. Update the net for D17 to match silkscreen.
    This should not affect the overall functionality of the board. =P
    [Arduino-Fio.brd, Arduino-Fio.sch]
2019-02-11 Update Arduino-Fio.brd
    Update labeling
    [Arduino-Fio.brd]
2020-02-12 Update Old FioV3 Examples
    - adjust the output for the hardware UART in **Blinkies.ino** file to distinguish betweeh the serial monitor
    - add `Keyboard.begin()` in `setup()` for **SimpleKeyboard_HID.ino** (this appears to work without initializing it but it was added to be consistent with Arduino's reference example)
    - add `Mouse.begin()` in `setup()` to **SimpleJoystickMouse_HID.ino** (this appears to work without initializing it but it was added to be consistent with Arduino's reference example)
    - include the ability to invert the mouse using the joystick depending on the orientation of the joystick
    -autoformat
    [Blinkies.ino, SimpleJoystickMouse_HID.ino, SimpleKeyboard_HID.ino]

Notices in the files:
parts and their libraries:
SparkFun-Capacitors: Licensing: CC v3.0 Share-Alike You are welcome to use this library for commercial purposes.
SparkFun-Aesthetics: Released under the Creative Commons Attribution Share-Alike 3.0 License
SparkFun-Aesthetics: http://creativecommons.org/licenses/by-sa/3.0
